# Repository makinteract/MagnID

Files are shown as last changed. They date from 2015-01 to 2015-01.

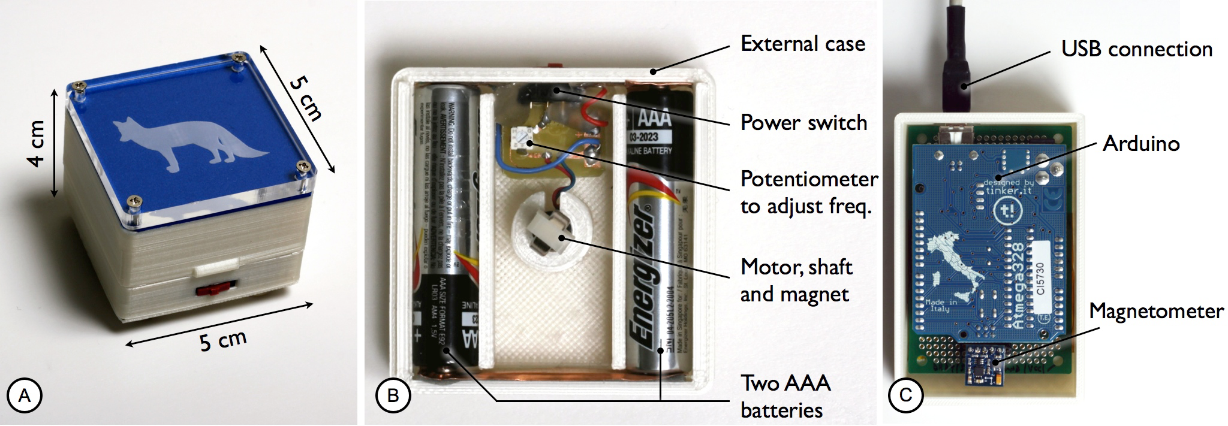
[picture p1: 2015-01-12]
Hardware/Tokens/Images/hardware.png

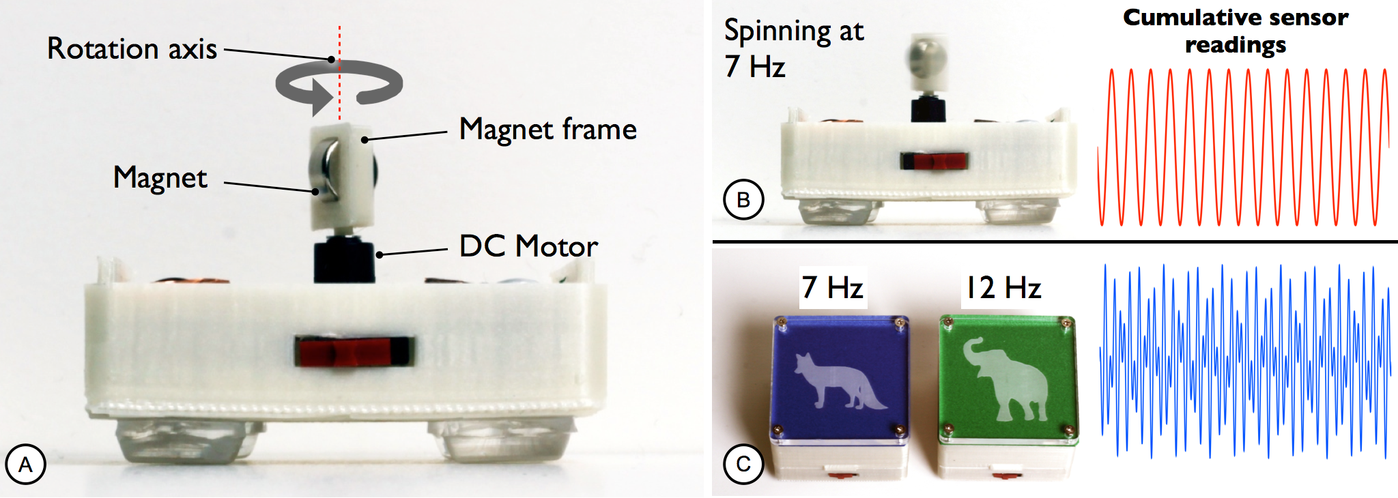
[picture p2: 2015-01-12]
Hardware/Tokens/Images/overview.png

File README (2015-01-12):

1) As stated in the license, the software is provided as is, without warranty of any kind.

2) At the moment, we do not offer any suport with the software. If you have problems with the installation or operating the software, we might not be able to help you or support you. The software comes as is. We however encourage you to check out this repository in future, as we are planning to add a tutorial session (or a video tutorial) - but it is only a plan for the moment.

3) We applied to a patent about the MagnID in the Republic of Korea in 2014. The patent is still pending.

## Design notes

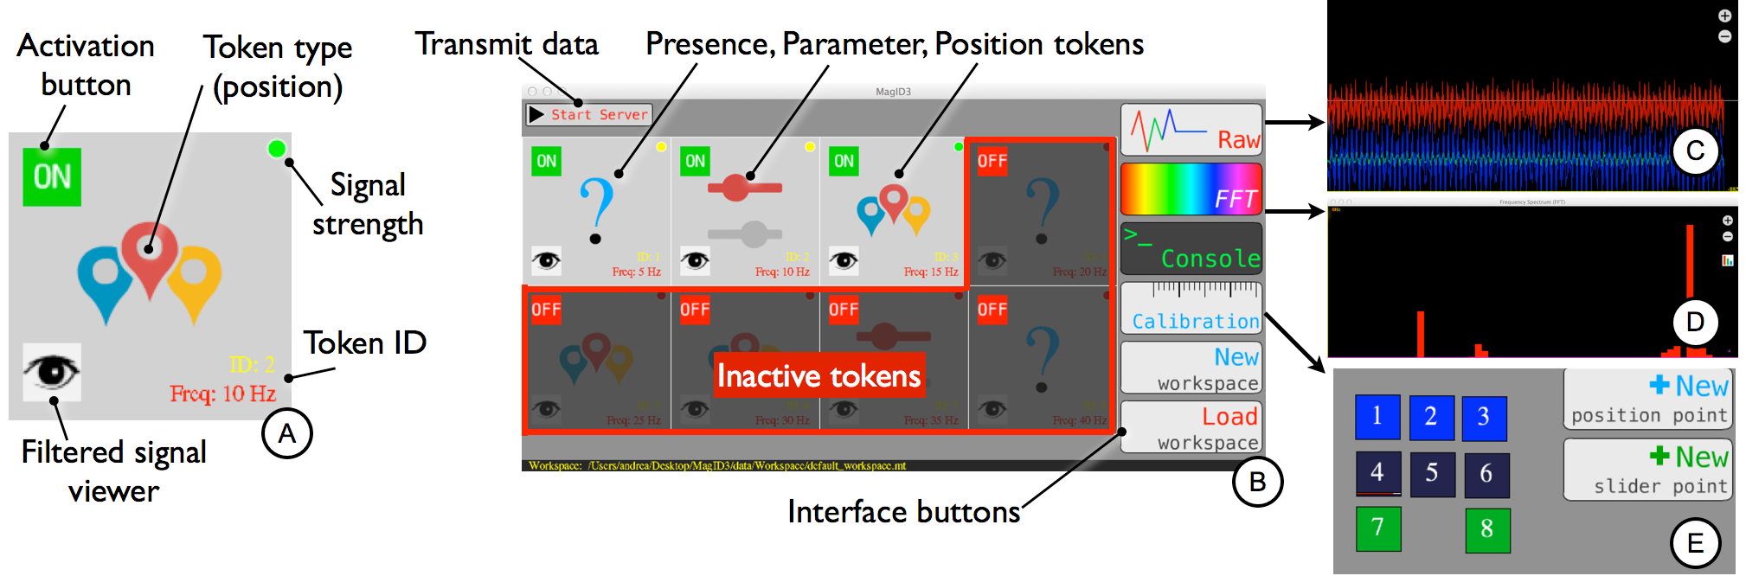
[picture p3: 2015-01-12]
Hardware/Tokens/Images/software.png

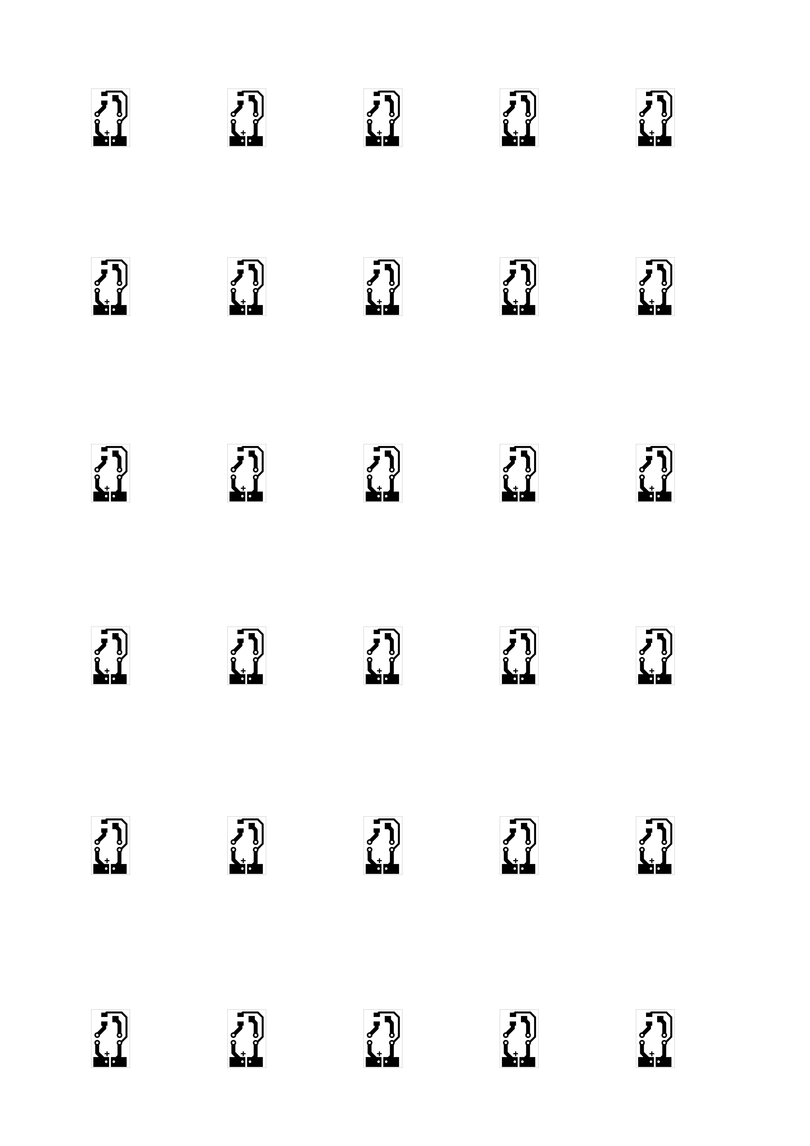
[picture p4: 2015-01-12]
Hardware/Tokens/PCB/pcb.png

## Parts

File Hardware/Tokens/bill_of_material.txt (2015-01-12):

Bill of Material (per MagnID token)

This material was purchased mostly on Korean websites. You can find alternatives or similar products also on other international websites.

1 x DC Motor (감속기어모터 6Ø모터 LCP06-A03V-0006)
http://devicemart.co.kr/goods/view.php?seq=1064545

1 x Switch (IMMS-12H)
http://devicemart.co.kr/goods/view.php?seq=2648

1 x 100Ω potentiometer (Bourns 3313J Series-100Ω)
http://devicemart.co.kr/goods/view.php?seq=20523

2 x AAA BATTERIES (LR03-2BP -AAA 1.5V- Be
http://devicemart.co.kr/goods/view.php?seq=2767

1 x magnet ND 7Ø x 3t (3mm depth) (they are sold 10 at a time)
http://ksstore.co.kr/front/php/product.php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

=> select the item 33번  - 240 won each

Other common parts:
1 x Copper tape (구리테이프 10mmX25m)
http://devicemart.co.kr/goods/view.php?seq=9505

1 x Double tape (3M double tape found in smart is fine)

1 x Copper board (구리판)
http://kitall.co.kr/goods/view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

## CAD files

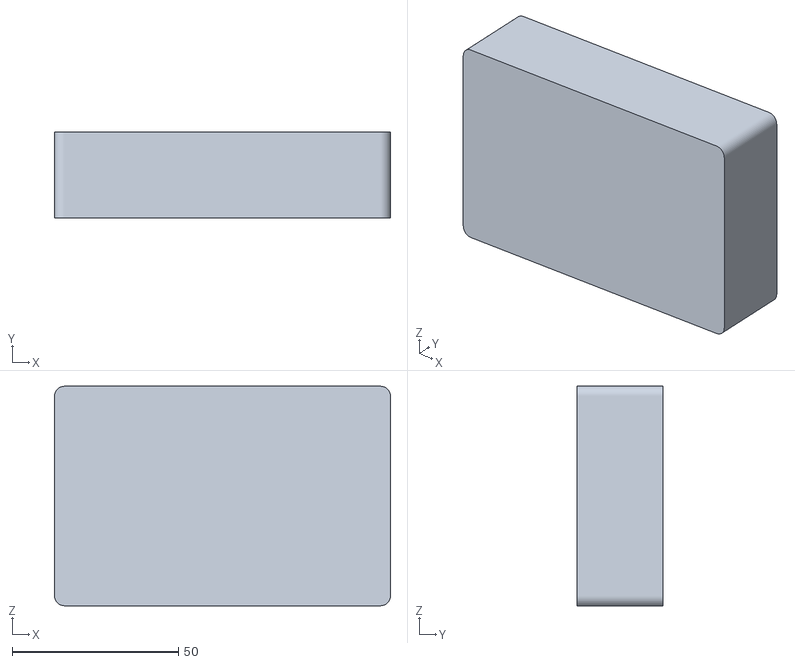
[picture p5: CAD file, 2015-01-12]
Hardware/Terminal/3Dmodels/magno_bottom.STL
101.0 x 26.0 x 66.0

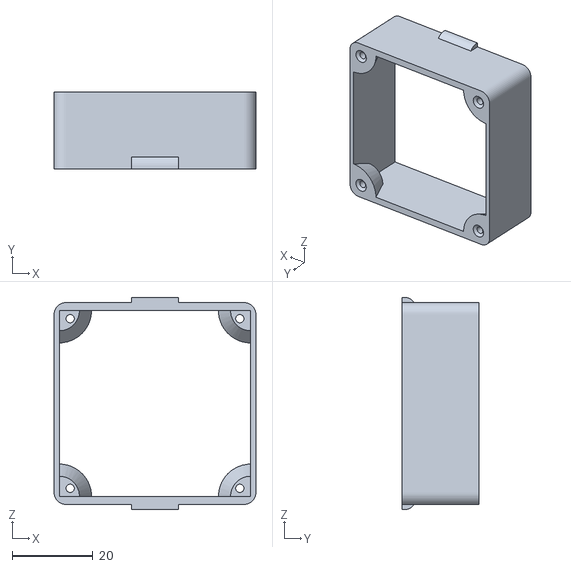
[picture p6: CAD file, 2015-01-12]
Hardware/Tokens/3Dmodels/token_top.STL
50.0 x 19.0 x 52.6

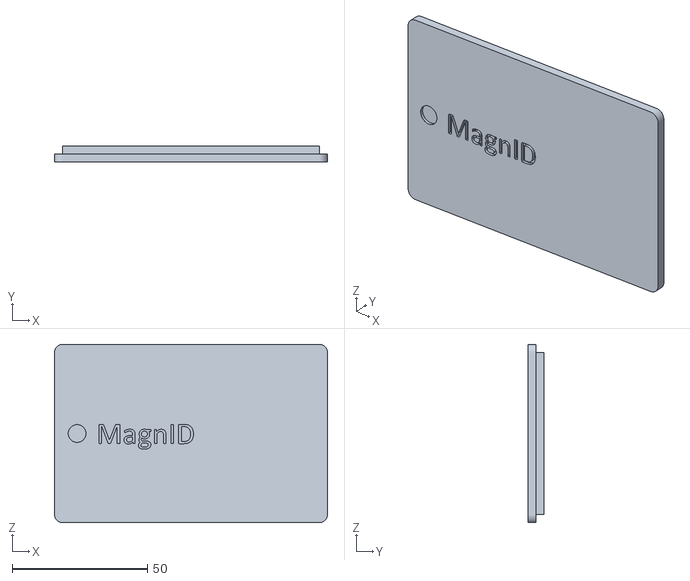
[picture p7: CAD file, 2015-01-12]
Hardware/Terminal/3Dmodels/magno_top.STL
101.0 x 6.00 x 66.0

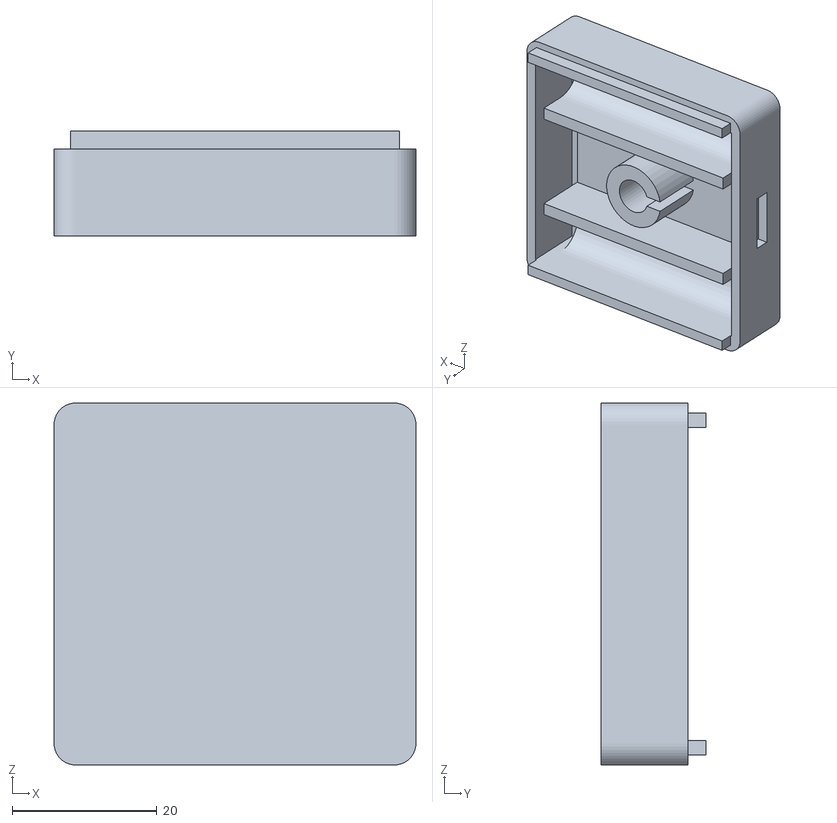
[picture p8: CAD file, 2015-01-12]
Hardware/Tokens/3Dmodels/token_bottom.STL
50.0 x 14.5 x 50.0

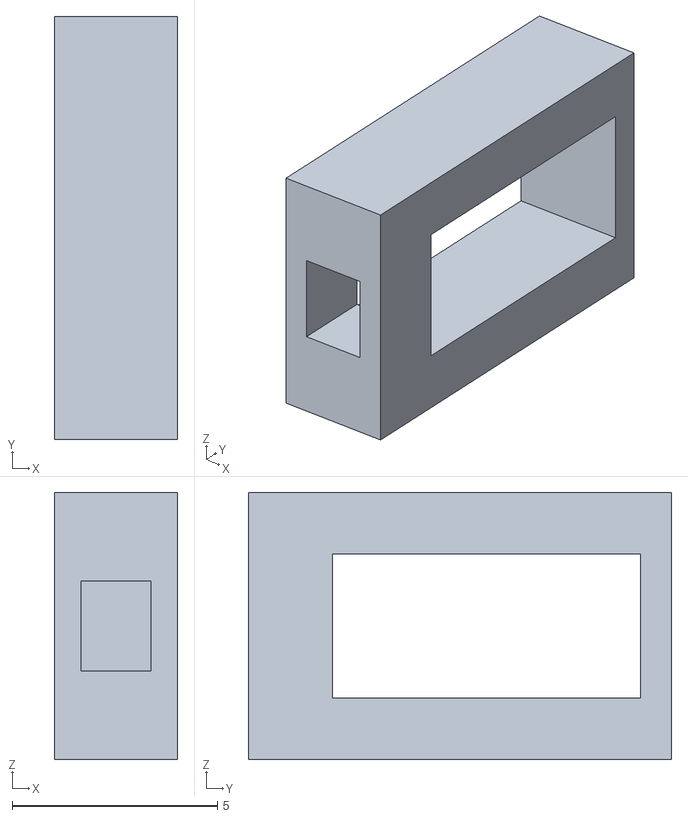
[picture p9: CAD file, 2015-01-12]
Hardware/Tokens/3Dmodels/shaft.STL
3.00 x 10.3 x 6.50

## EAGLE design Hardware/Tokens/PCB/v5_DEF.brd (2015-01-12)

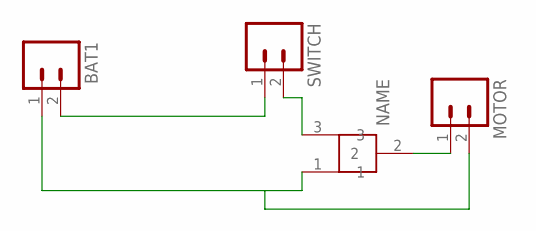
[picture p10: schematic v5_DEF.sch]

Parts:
BAT1: M02-JST-2-PTH-NO_SILK; JST-2-PTH-NS
MOTOR: M02-JST-2-PTH-NO_SILK; JST-2-PTH-NS
SWITCH: M02-JST-2-PTH-NO_SILK; JST-2-PTH-NS
U$1: BOURNS3313JBOURNS3313J; BOURNS3313J

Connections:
GND: BAT1.1, MOTOR.2, U$1.1
unnamed: BAT1.2, SWITCH.1
unnamed: SWITCH.2, U$1.3
unnamed: MOTOR.1, U$1.2

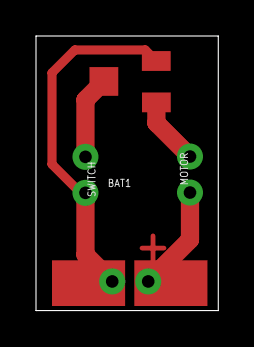
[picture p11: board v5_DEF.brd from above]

Board: 2 copper layers, 10.1 x 15.3 mm, 4 parts (0 on the bottom side), 4 nets.

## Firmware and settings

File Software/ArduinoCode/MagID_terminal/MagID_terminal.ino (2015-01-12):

#include <Wire.h>

#define MAG_ADDRESS ((char) 0x1E)
uint8_t mag_buffer[6];
int16_t mag_raw[3];

long start_time = 0;
long previous_time = 0;
long loop_duration = 0;

volatile boolean isDataReady = true;

void setup() {
  Serial.begin(115200);
  //Serial.println("Initializing...");
  
  Wire.begin();

  configMag();
  
  attachInterrupt(0, magDataReady, CHANGE);
  
  previous_time = micros();
}


//interrupt function when mag DRDY pin is brought LOW
void magDataReady() {
  isDataReady = true;
}


void loop() {
  interrupts();
  start_time = micros();
  loop_duration = start_time - previous_time;
  
  if(loop_duration >= 10000) { // change 10000 to have 100Hz sampling, 5000 to have 200Hz sampling etc...
    if(isDataReady) {
      isDataReady = false;
      readMag();
  
      Serial.print(mag_raw[0], DEC); Serial.print(",");
      Serial.print(mag_raw[1], DEC); Serial.print(",");
      Serial.println(mag_raw[2], DEC); Serial.println();
      previous_time = start_time;



    }
    else {
      //Serial.println("Missed one");

    }
  }
  
}


void configMag() {
  uint8_t mag_name;
  
  // make sure that the device is connected
  Wire.beginTransmission(MAG_ADDRESS); 
  Wire.write((byte) 0x0A); // Identification Register A
  Wire.endTransmission();
  
  Wire.beginTransmission(MAG_ADDRESS);
  Wire.requestFrom(MAG_ADDRESS, 1);
  mag_name = Wire.read();
  Wire.endTransmission();
  
  if(mag_name != 0x48) {
    Serial.println("HMC5883L not found!");
    Serial.print(mag_name, HEX); Serial.println(" found, should be 0x48");
    delay(1000);
  }
  
  // Register 0x00: CONFIG_A
  // normal measurement mode (0x00) and 75 Hz ODR (0x18)
  Wire.beginTransmission(MAG_ADDRESS);
  Wire.write((byte) 0x00);
  Wire.write((byte) 0x18);
  Wire.endTransmission();
  delay(5);
  
  // Register 0x01: CONFIG_B
  // default range of +/- 130 uT (0x20)
  Wire.beginTransmission(MAG_ADDRESS);
  Wire.write((byte) 0x01);
  Wire.write((byte) 0x20);
  Wire.endTransmission();
  delay(5);
  
  // Register 0x02: MODE
  // continuous measurement mode at configured ODR (0x00)
  // possible to achieve 160 Hz by using single measurement mode (0x01) and DRDY
  Wire.beginTransmission(MAG_ADDRESS);
  Wire.write((byte) 0x02);
  Wire.write((byte) 0x01);
  Wire.endTransmission();
  
  delay(200);
}


// read 6 bytes (x,y,z magnetic field measurements) from the magnetometer
void readMag() {
  
  // multibyte burst read of data registers (from 0x03 to 0x08)
  Wire.beginTransmission(MAG_ADDRESS);
  Wire.write((byte) 0x03); // the address of the first data byte
  Wire.endTransmission();
  
  Wire.beginTransmission(MAG_ADDRESS);
  Wire.requestFrom(MAG_ADDRESS, 6);  // Request 6 bytes
  int i = 0;
  while(Wire.available() >0 && i < 6) 
  { 
    mag_buffer[i] = Wire.read();  // Read one byte
    i++;
  }
  Wire.read();
  Wire.endTransmission();
  
  // combine the raw data into full integers (HMC588L sends MSB first)
  //           ________ MSB _______   _____ LSB ____
  mag_raw[0] = (mag_buffer[0] << 8) | mag_buffer[1];
  mag_raw[1] = (mag_buffer[2] << 8) | mag_buffer[3];
  mag_raw[2] = (mag_buffer[4] << 8) | mag_buffer[5];
  
  // put the device back into single measurement mode
  Wire.beginTransmission(MAG_ADDRESS);
  Wire.write((byte) 0x02);
  Wire.write((byte) 0x01);
  Wire.endTransmission();
}

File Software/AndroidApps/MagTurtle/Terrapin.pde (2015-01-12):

final int TERRAPIN_CMD_NONE     = 0;
final int TERRAPIN_CMD_MOVE     = 1;
final int TERRAPIN_CMD_ROTATE   = 2;

int TERRAPIN_MOVE_SMALL   = 15; // used for circle
int TERRAPIN_MOVE_MEDIUM  = 75; // used for small shapes or shapes with two lines (small move is to tiny for most purposes)
int TERRAPIN_MOVE_LARGE   = 200; // used for most shapes

final int TERRAPIN_ROTATE_1     = 9; // used for circle, star - bit of a wierd choice.... 
final int TERRAPIN_ROTATE_2     = 30; // used for triangle
final int TERRAPIN_ROTATE_3     = 45; // used for flower
final int TERRAPIN_ROTATE_4     = 90; // used for square, triangle
final int TERRAPIN_ROTATE_5     = 155; // used for flower - this angle is a wierd choice, but makes the flower.... 

// how fast we move and turn
float moveRate = 3; // we have a bug here. If the move rate is low the whole thing gets screwed up. Why? God knows. 
float turnRate = 3; // this is in degrees 

class terrapinCommand
  {
  int type; 
  int value;
  float progress;
  int totalAdj; 
  
  public terrapinCommand(int t, int v) 
    {
    type = t;
    value = v;   
    progress = 0; // no progress
    totalAdj = 0; 
    }  
    
  int evaluateCommand()
    {
    if (progress>=1.0)
      return 0;   
      
    int oldProg = (int)(progress*(float)value);
    if (type == TERRAPIN_CMD_MOVE) progress += (float)moveRate / (float)value;
    else progress += (float)turnRate / (float)value; //rotationrate by default
    int newProg = (int)(progress*(float)value);
        
    int adj = newProg-oldProg;
    int newTotalAdj=totalAdj+newProg-oldProg; 
    if (newTotalAdj>abs(value))
      adj=value-totalAdj;
    totalAdj += adj;  
      
    if (type == TERRAPIN_CMD_ROTATE && value<0)
      adj*=-1; // this is left rotation
      
    return adj; 
    }
    
    
  };








public class Terrapin 
  {
    
  public float x;
  public float y;
  public float rotation;
  
  float sx;
  float sy;
  float sr;
  
  public boolean drawing = true;
  public int drawColor;
    
  PGraphics buffer;
  
  ArrayList<terrapinCommand> moves;
  boolean running;// whether we are processing the moves. 
  
  PShape turtle;
  
  public Terrapin(int w, int h, int xp, int yp) 
    {
    buffer = createGraphics(w, h);
    beginDrawing();
      clearDrawing();
    endDrawing();
    
    configMovement();
    x = xp;
    y = yp;
    rotation = 0;
    sx=x;
    sy=y;
    sr=rotation;
    drawColor = color(0, 0, 255);
    moves = new ArrayList(); 
    running = false;
    
    // load the turtle icon
    turtle = loadShape("turtle.svg");
    }
 
 void configMovement()
  {
      TERRAPIN_MOVE_SMALL = buffer.width/40; 
      TERRAPIN_MOVE_MEDIUM = TERRAPIN_MOVE_SMALL*5;
      TERRAPIN_MOVE_LARGE = (int)((float)TERRAPIN_MOVE_MEDIUM*2.25); 
      
      moveRate = buffer.width/200; 
      //println(moveRate); 
  } 
    
 void clearBlocks()
   {moves.clear(); running=false;}
   
 void addBlock(int t, int v)
     {moves.add(new terrapinCommand(t, v));} 
     
 boolean isBlocks()
   {return moves.size()>0;}
  
 // reset everything 
 void resetTerrapin()
  {
  clearBlocks(); // empty previous tokens
  clearDrawing(); // blank the previous drawing 
  resetPosition(); // go back to start pos/angle 
  } 
  
 void startRunning()
   {running = true;}
 
 boolean atStartPoint() 
   {
   //println(x +","+ y +","+ rotation%360); 
   return (round(x)==round(sx) && round(y)==round(sy) && round(rotation%360)==round(sr%360));
   }
   
 void resetPosition()
   {
     x=sx;
     y=sy;
     rotation=sr; 
   } 
   
   
  void beginDrawing()     {buffer.beginDraw();}
  void endDrawing()       {buffer.endDraw();}
  void clearDrawing()     {buffer.background(200);}
  PImage getBuffer()      {return buffer.get(0,0,buffer.width,buffer.height);}
  int getBufferWidth()    {return buffer.width;}
  int getBufferHeight()   {return buffer.height;}
  
  PImage getBufferTurtle()
    {
      int startx = (int)x-buffer.width/32-10; 
      int starty = (int)y-buffer.width/32-10; 
      return buffer.get(startx,starty,buffer.width/16+20,buffer.width/16+20);
    }
  
  
  public void setLocation(int x, int y) {this.x = x; this.y = y;}
  
  public void left(int amount) {rotation -= amount;}
  public void right(int amount) {rotation += amount;}
 
  public void backward(int amount) {forward(-amount);}
  public void forward(int amount) 
    {
    float newX, newY;
    float rotRad = radians(rotation);
    newX = x + amount * cos(rotRad);
    newY = y + amount * sin(rotRad);
    moveTo(newX, newY);
    }
    
  public float getRotation() {return rotation;}
  public void setRotation(int rotation) {this.rotation = rotation;}
  
  public void strafeLeft(int amount) {left(90);forward(amount);right(90);}
  public void strafeRight(int amount) {right(90);forward(amount);left(90);}
  
  protected void moveTo(float x, float y) 
    {
      if (drawing) 
        {
          //println("Draw " +x); 
        buffer.stroke(drawColor);
        buffer.strokeWeight(1);
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

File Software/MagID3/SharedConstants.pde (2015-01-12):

// 1. MODIFIABLE DEFAULT VALUES (change them in config.xml)

// TOKENS
static int FFT_SIZE = 128;
static int SAMPLIG_FREQ= 100;
static int FFT_WINDOW= 1024;
static int FIX_FREQ_TOKEN_TIME_FILTER_WINDOW_MS=100;
static float LOW_STRENGHT_SIGNAL=10;
static float HIGH_STRENGHT_SIGNAL=30;

static int CALIBRATION_TOKEN= 1; // ID 1, location 2
static int TOT_CALIBRATION_POINTS= 100;

static int REFRESH_MS = 250;


// NETWORK
static int SERIAL_PORT=8;
static int OSC_PORT= 5204;
static String MULTICAST_ADDRESS="239.0.0.1";

// SERIAL
static int BAUD_RATE= 115200; 

// FILE
static String WORKSPACE_DIR="Workspace/";
static String FILTERS_DIR="Filters/";


// 2. CONSTANTS NOT MODIFIABLE

// MAIN INTERFACE
final int WIDTH=1000;
final int HEIGHT=500;
final int HOME_BUTTON_WIDTH=200;
final int HOME_BUTTON_HEIGHT=80;
final int TOKEN_SIZE=200;
final int NUMBER_OF_TOKENS=8;
final int STATUS_BAR_HEIGHT= 15;

// COLORS
final color RED= color(255, 0, 0);
final color GREEN= color(0, 255, 0);
final color BLUE= color(0, 0, 255);
final color YELLOW= color(255, 255, 0);
final color BLACK= color(0, 0, 0);
final color WHITE= color(255, 255, 255);
final color PURPLE= color(255, 0, 255);
final color DARK_GREY= color(30, 30, 30);
final color GREY= color(128, 128, 128);
final color LIGHT_GREY= color(200, 200, 200);
final color DARK_GREEN= color(0, 163, 26);

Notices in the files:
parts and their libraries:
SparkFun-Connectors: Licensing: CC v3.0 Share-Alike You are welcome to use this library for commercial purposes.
